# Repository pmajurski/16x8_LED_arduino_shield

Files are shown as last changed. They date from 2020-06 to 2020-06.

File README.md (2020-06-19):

# 16x8_LED_arduino_shield
16x8 LED display shield for Arduino Uno 

# Overview
This project is a custom shield for the Arduino Uno R3 and the controlling code. The display is two LuckyLight 8x8 LED matrices driven by two MAX7219 chips. Inputs for directional control, mode select, and brightness.
The display runs creatively named "display processes" which are relatively easy to create and add in. Display processes are broken up into animations and games. Animations can be static images, looping sequences of frames (ie gif), or animated sprites. Animations are non-interactive and ignore directional input. Games are interactive and use directional input.

# Controls
- Select toggles directional input between the current running process and mode select.
- Mode select: left / right cycles between animations, up / down cycles between games.
- Games are paused during mode select. Pressing select will unpause the active process. Animations ignore pause and will run during mode select.
- Brightness controls increase / decrease brightness. Default brightness can be adjusted in DisplayDriver.h

# Specs
- Display refresh and input polling at 50 Hz
- Powered by barrel jack connected to 9V battery. Optionally powered by Arduino Uno's barrel jack or USB.
- Display resolution of 16x8 pixels. Coordinate system is (y,x) with origin at top left corner. Y increases down, x increases right.
- Display draws roughly 340mA at full brightness.
 
# Creating new display processes
- Create a new child class of DisplayProcess
- Update animeProcesses or gameProcesses and their corresponding counts in .ino file.
- Display can be written to via a 16x8-bit frame buffer or 16x8-byte game matrix (which is then written to the frame buffer). 
- All processes share the frame buffer and game matrix.
- Sprites.cpp contains full frames stored in PROGMEM, which can be loaded directly into the frame buffer.

# Datasheets
- [MAX7219](https://www.sparkfun.com/datasheets/Components/General/COM-09622-MAX7219-MAX7221.pdf)
- [LuckyLight 8x8 LED matrix](https://cdn-shop.adafruit.com/datasheets/1820_KWM-R30881XPGB.pdf)

# Acknowledgements
- [forrestbao's kicad Arduino Uno shield footprint](https://github.com/forrestbao/arduino-kicad-library)
- [Adafruit Mini LED Gamer](https://github.com/adafruit/Adafruit_Learning_System_Guides/tree/master/Mini_LED_Gamer) - code for interrupt setup and modified snake game
- [MAX7219 driver wiring set up](https://playground.arduino.cc/Main/MAX72XXHardware/)

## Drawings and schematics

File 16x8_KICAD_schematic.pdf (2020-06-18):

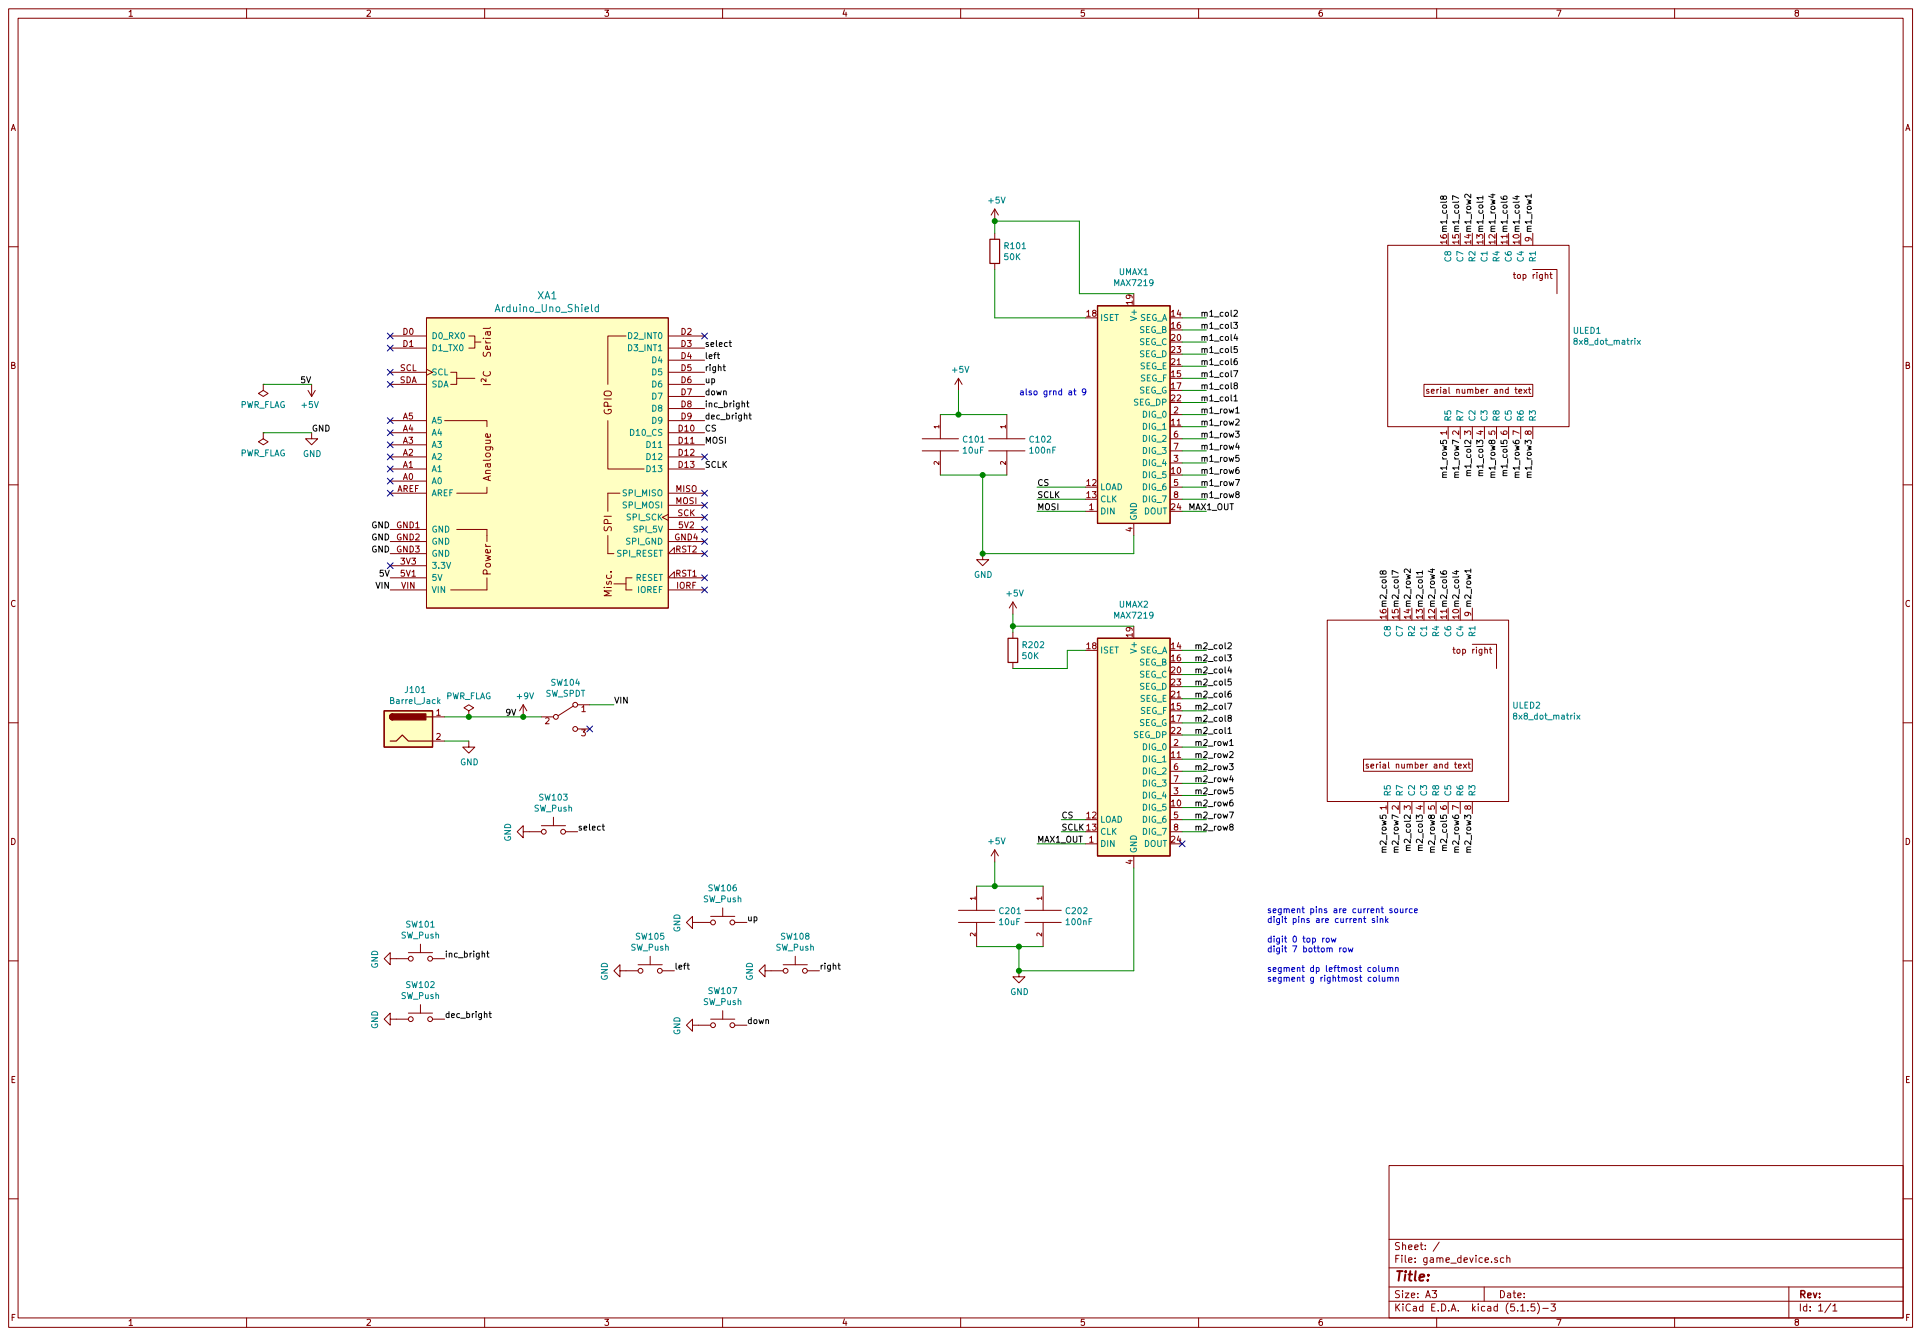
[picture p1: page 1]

serial number and text

segment pins are current source
digit pins are current sink

segment dp leftmost column
segment g rightmost column

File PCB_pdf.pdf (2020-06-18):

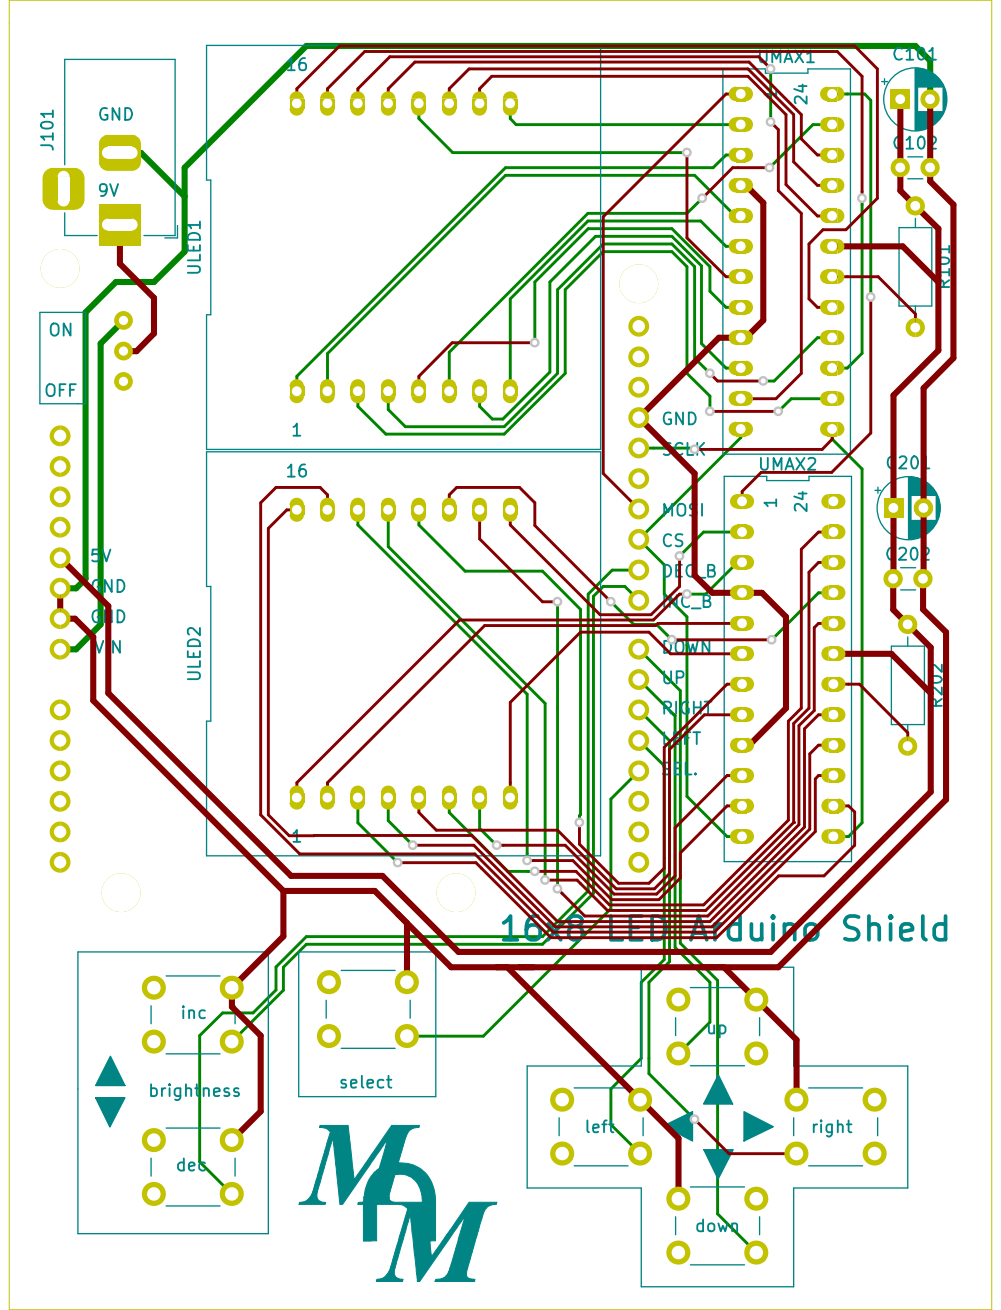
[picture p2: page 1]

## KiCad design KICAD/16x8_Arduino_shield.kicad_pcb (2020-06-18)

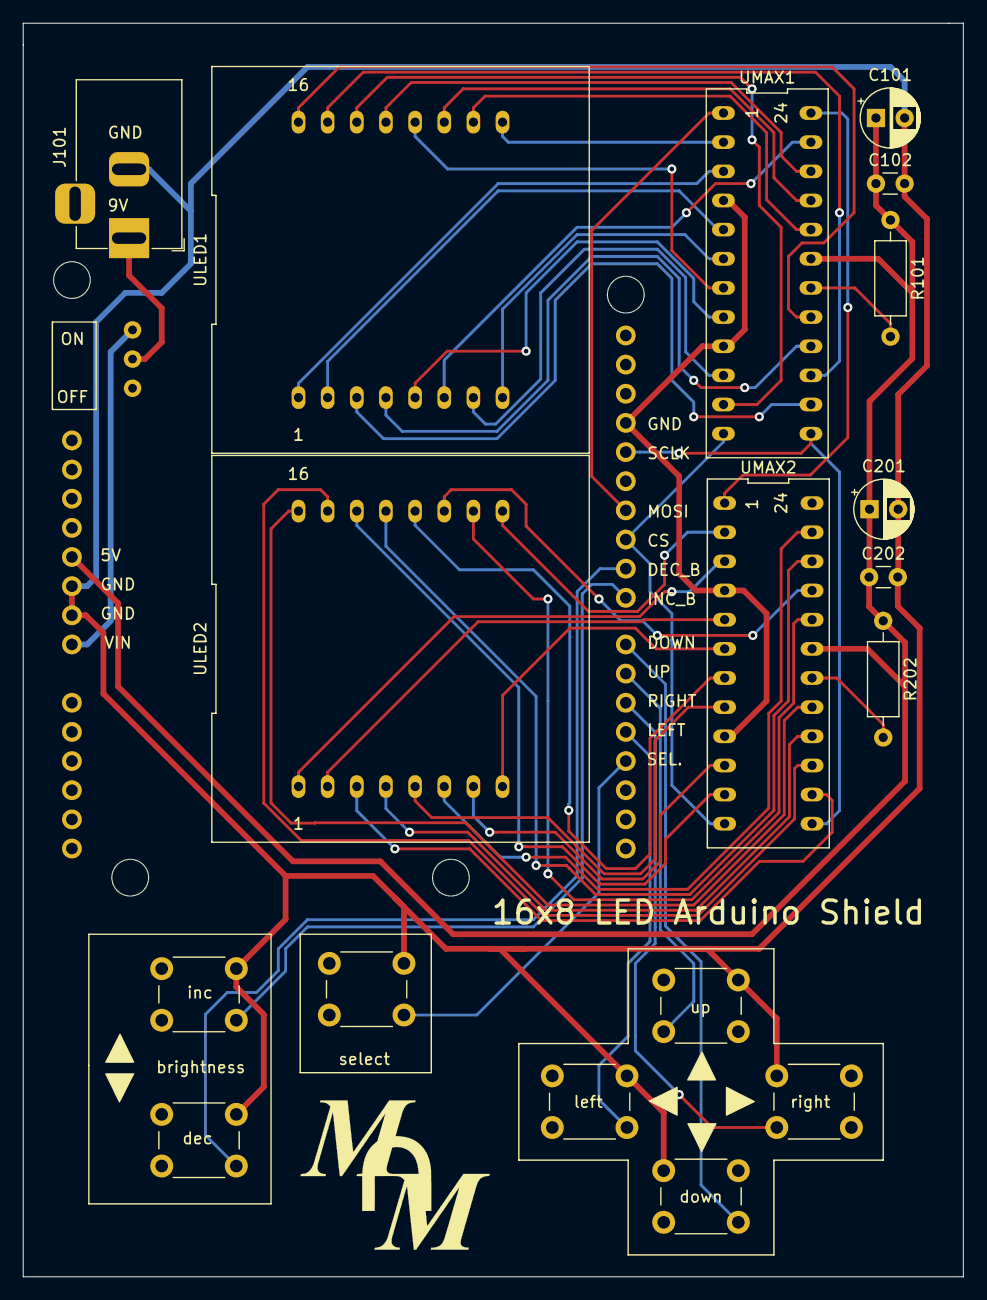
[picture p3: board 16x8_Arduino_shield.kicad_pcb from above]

Board: 2 copper layers, 81.9 x 109.2 mm, 20 parts (0 on the bottom side), 49 nets.

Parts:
C101, C201: 10uF; CP_Radial_D5.0mm_P2.50mm
C102, C202: 100nF; C_Disc_D3.0mm_W1.6mm_P2.50mm
J101: Barrel_Jack; BarrelJack_Horizontal
R101, R202: 50K; R_Axial_DIN0207_L6.3mm_D2.5mm_P10.16mm_Horizontal
SW104: SW_SPDT; SPDT_switch_custom
ULED1, ULED2: 8x8_dot_matrix; LuckyLight_8x8_LED_matrix
UMAX1, UMAX2: MAX7219; MAX2719_custom
XA1: Arduino_Uno_Shield
dec: SW_Push; SW_PUSH_6mm
down: SW_Push; SW_PUSH_6mm
inc: SW_Push; SW_PUSH_6mm
left: SW_Push; SW_PUSH_6mm
right: SW_Push; SW_PUSH_6mm
select: SW_Push; SW_PUSH_6mm
up: SW_Push; SW_PUSH_6mm

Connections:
+5V: C101.1, C102.1, C201.1, C202.1, R101.1, R202.1, UMAX1.19, UMAX2.19, XA1.5V1
+9V: J101.1, SW104.2
/CS: UMAX1.12, UMAX2.12, XA1.D10
/MAX1_OUT: UMAX1.24, UMAX2.1
/MOSI: UMAX1.1, XA1.D11
/SCLK: UMAX1.13, UMAX2.13, XA1.D13
/VIN: SW104.1, XA1.VIN
/dec_bright: XA1.D9, dec.2
/down: XA1.D7, down.2
/inc_bright: XA1.D8, inc.2
/left: XA1.D4, left.2
/m1_col1: ULED1.13, UMAX1.22
/m1_col2: ULED1.3, UMAX1.14
/m1_col3: ULED1.4, UMAX1.16
/m1_col4: ULED1.10, UMAX1.20
/m1_col5: ULED1.6, UMAX1.23
/m1_col6: ULED1.11, UMAX1.21
/m1_col7: ULED1.15, UMAX1.15
/m1_col8: ULED1.16, UMAX1.17
/m1_row1: ULED1.9, UMAX1.2
/m1_row2: ULED1.14, UMAX1.11
/m1_row3: ULED1.8, UMAX1.6
/m1_row4: ULED1.12, UMAX1.7
/m1_row5: ULED1.1, UMAX1.3
/m1_row6: ULED1.7, UMAX1.10
/m1_row7: ULED1.2, UMAX1.5
/m1_row8: ULED1.5, UMAX1.8
/m2_col1: ULED2.13, UMAX2.22
/m2_col2: ULED2.3, UMAX2.14
/m2_col3: ULED2.4, UMAX2.16
/m2_col4: ULED2.10, UMAX2.20
/m2_col5: ULED2.6, UMAX2.23
/m2_col6: ULED2.11, UMAX2.21
/m2_col7: ULED2.15, UMAX2.15
/m2_col8: ULED2.16, UMAX2.17
/m2_row1: ULED2.9, UMAX2.2
/m2_row2: ULED2.14, UMAX2.11
/m2_row3: ULED2.8, UMAX2.6
/m2_row4: ULED2.12, UMAX2.7
/m2_row5: ULED2.1, UMAX2.3
/m2_row6: ULED2.7, UMAX2.10
/m2_row7: ULED2.2, UMAX2.5
/m2_row8: ULED2.5, UMAX2.8
/right: XA1.D5, right.2
/select: XA1.D3, select.2
/up: XA1.D6, up.2
GND: C101.2, C102.2, C201.2, C202.2, J101.2, UMAX1.4, UMAX1.9, UMAX2.4, UMAX2.9, XA1.GND1, XA1.GND2, XA1.GND3, dec.1, down.1, inc.1, left.1, right.1, select.1, up.1
unnamed: R101.2, UMAX1.18
unnamed: R202.2, UMAX2.18

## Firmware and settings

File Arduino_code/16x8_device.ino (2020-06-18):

#include "Arduino.h"
#include "displayprocess.h"
#include "beatingheart.h"
#include "snake.h"
#include "mazegame.h"
#include "mugwithsteam.h"
#include "inchworm.h"
#include "icicles.h"
#include "screensaver.h"
#include "dwarfface.h"

using namespace DirectionInput;  //enum namespace for DisplayProcess move inputs

//defines pin numbers for input signals
enum InputSignal: uint8_t {
    SELECT_BUTTON = 3,
    LEFT_BUTTON = 4,
    RIGHT_BUTTON = 5,
    UP_BUTTON = 6,
    DOWN_BUTTON = 7,
    INCREASE_BRIGHTNESS = 8,
    DECREASE_BRIGHTNESS = 9,
    NO_SIGNAL = 255  //pin number 255 does not exist, used as no input
};

const uint8_t NUM_INPUTS = 7;  //number input pins used
const InputSignal INPUT_PINS[] = {
        SELECT_BUTTON,
        LEFT_BUTTON,
        RIGHT_BUTTON,
        UP_BUTTON,
        DOWN_BUTTON,
        INCREASE_BRIGHTNESS,
        DECREASE_BRIGHTNESS
};

//definite debounce and input cooldown
const uint8_t INPUT_COOLDOWN_CYCLES = 5;  //in refresh cycles - 5 = 100ms
const uint8_t DEBOUNCE_DELAY = 3;  //debounce minimum cycles for active state to count as valid input signal

//display processes available; MINIMUM of one of each process
DisplayProcess *gameProcesses[] = {
        new Snake(),
        new MazeGame()
};
DisplayProcess *animeProcesses[] = {
        new MugWithSteam(),
        new InchWorm(),
        new BeatingHeart(),
        new Icicles(),
        new ScreenSaver(),
        new DwarfFace()
};

const uint8_t NUM_GAMES = 2;
const uint8_t NUM_ANIMES = 6;
const uint8_t INITAL_ANIME = 5;  //index of anime process loaded on power up

uint8_t currentGame = 0;  //game process active or last active when in anime process
uint8_t currentAnime = INITAL_ANIME;  //anime process active or last active when in game process
DisplayProcess *activeProcess = animeProcesses[currentAnime];  //boots into an animation

//ISR volatile variables
volatile bool refreshDisplay = false;
volatile bool modeSelect = false;

//input handler variables
volatile uint8_t buttonHoldTimes[NUM_INPUTS] = {0};  //corresponds to elements of INPUT_PINS
volatile InputSignal inputBuffer = NO_SIGNAL;
volatile uint8_t inputCooldown = 0;

//enum type used for input directions in display processes
MoveDirection moveDirection = NO_INPUT;


//function prototypes
void inputHandler();  //iterates over signal pins looking for active pins
void processButton(uint8_t pinIndex);  //reads pins and debounces
void switchProcess();  //changes active display process
uint8_t getProcessIndex(uint8_t size, uint8_t index, bool direction);  //finds next display process
void setup();
void loop();


//50Hz timer interrupt for refreshing display
ISR(TIMER1_OVF_vect) {
  inputHandler();  //reads input signals. Buffers valid debounced inputs
  refreshDisplay = true;  //next loop() display process updates
}

void inputHandler() {
  inputBuffer = NO_SIGNAL;

  if (inputCooldown == 0) {  //cooldown since last input has expired; new input is accepted
    for (uint8_t i = 0; i < NUM_INPUTS; ++i) {  //read current button states; iterates over INPUT_PINS
      processButton(i);  //reads, debounces input signal

      if (inputBuffer != NO_SIGNAL)  //exits input handler if signal is valid
        return;
    }
  }
  else {  //cooldown between button presses is not over
    inputCooldown--;
  }
}

void processButton(uint8_t pinIndex) {
  if (digitalRead(INPUT_PINS[pinIndex]) == LOW) {  //determines if input is active
    buttonHoldTimes[pinIndex]++;

    if (buttonHoldTimes[pinIndex] > DEBOUNCE_DELAY) {  //signal active for longer than debounce period
      inputBuffer = INPUT_PINS[pinIndex];
      inputCooldown = INPUT_COOLDOWN_CYCLES;

      for (uint8_t j = 0; j < NUM_INPUTS; ++j)  //resets button hold times
        buttonHoldTimes[j] = 0;
    }
  }
  else {  //input signal is inactive, button hold time is reset
    buttonHoldTimes[pinIndex] = 0;
  }
}

void switchProcess() {
  switch (moveDirection) {  //computes next process index and updates activeProcess
    case LEFT:  //previous anime
      currentAnime = getProcessIndex(NUM_ANIMES, currentAnime, 0);
      activeProcess = animeProcesses[currentAnime];
      break;
    case RIGHT:  //next anime
      currentAnime = getProcessIndex(NUM_ANIMES, currentAnime, 1);
      activeProcess = animeProcesses[currentAnime];
      break;
    case UP:  //next game
      currentGame = getProcessIndex(NUM_GAMES, currentGame, 1);
      activeProcess = gameProcesses[currentGame];
      break;
    case DOWN:  //previous game
      currentGame = getProcessIndex(NUM_GAMES, currentGame, 0);
      activeProcess = gameProcesses[currentGame];
  }

  activeProcess->init();  //init new process
}

uint8_t getProcessIndex(uint8_t size, uint8_t index, bool direction) {
  //returns new index; handles wrap around logic
  //direction: 1-increments; 0-decrements
  if (direction) {  //forward move
    if (index < size - 1)
      return ++index;
    return 0;  //wraps around to beginning of array
  }
  else {  //backwards move
    if (index != 0)
      return --index;
    return (size - 1);  //wraps around to end of array
  }
}

void setup() {
  //configures all input pins as active low with internal pullup
  for (uint8_t i = 0; i < NUM_INPUTS; ++i)
    pinMode(INPUT_PINS[i], INPUT_PULLUP);

  randomSeed(analogRead(5));  //seeds random generation with unconnected pin
  for (uint8_t i = 0; i < 4; ++i) //skips first randoms, always same
    random();


  // taken from https://github.com/adafruit/Adafruit_Learning_System_Guides/blob/master/Mini_LED_Gamer/
  // ADC clock configurations
  byte ADPS_32 = _BV(ADPS2)|_BV(ADPS0);
  byte ADPS_128 = _BV(ADPS2)|_BV(ADPS1)|_BV(ADPS0);

  //ADC: 16MHz/16=1MHz
  ADCSRA &= ~ADPS_128;              // clean out ADPS
  ADCSRA |= ADPS_32;                // set Division Factor

  // Timer1 overflow interrupt setup
  TCNT1 = 0;                        // reset the counter
  ICR1 = 19999;                     // top value of the counter (16*10^6Hz/2000000*20000us/8-1) -> 1/20000us = 50Hz
  TCCR1A = 0;                       // clear TCCR1A (not used)
  TCCR1B = _BV(WGM13) | _BV(CS11);  // mode 8(PWM), set prescalar=8;
  TIMSK1 = _BV(TOIE1);              // Enable Overflow Interrupt


  activeProcess->init();  //start first display process
}

void loop() {
  if (refreshDisplay) {
    moveDirection = NO_INPUT;

    //interprets input signal
    switch (inputBuffer) {  //only 1 input signal can be generated at a time
      case SELECT_BUTTON:
        if (modeSelect)  //leaving mode select
          activeProcess->unpause();
        else  //entering mode select
          activeProcess->pause();
        modeSelect = !modeSelect;  //switches how directional input is handled
        break;
      case INCREASE_BRIGHTNESS:
        DisplayProcess::increaseBrightness();
        break;
      case DECREASE_BRIGHTNESS:
        DisplayProcess::decreaseBrightness();
        break;
      case LEFT_BUTTON:
        moveDirection = LEFT;
        break;
      case RIGHT_BUTTON:
        moveDirection = RIGHT;
        break;
      case UP_BUTTON:
        moveDirection = UP;
        break;
      case DOWN_BUTTON:
        moveDirection = DOWN;
    }

    //direction input is handled differently in mode select. the current display process is changed and init
    if (modeSelect and moveDirection != NO_INPUT)
      switchProcess();  //changes active process
    else
      activeProcess->run(moveDirection);  //updates process, stepping one frame

    refreshDisplay = false;
  }
}

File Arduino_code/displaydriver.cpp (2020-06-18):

#include "displaydriver.h"

DisplayDriver::DisplayDriver() {
  intensity_ = DEFAULT_INTENSITY;
  configSPI();
  disableDisplayTest();  //prevents LED displays being placed into display test mode on uploading code to Arduino
  configDisplay();
  clearDisplay();
}

void DisplayDriver::configSPI() {
  //SPI.begin();

  //configures SPI pins
  pinMode(CHIP_SELECT, OUTPUT);
  pinMode(MASTEROUT_SLAVEIN, OUTPUT);
  pinMode(SERIAL_CLK, OUTPUT);
  digitalWrite(CHIP_SELECT, LOW);  //drives CHIP_SELECT (LOAD on MAX7219) low

}

void DisplayDriver::configDisplay() {
  //transmits op codes to set intensity, disable shutdown, set scan all digits
  uint16_t intensity = INTENSITY_REG + intensity_;
  uint16_t spiData[] = {intensity, intensity, SCAN_ALL, SCAN_ALL, SHUTDOWN_DISABLE, SHUTDOWN_DISABLE};
  spiTransmit(spiData, 6);
}

void DisplayDriver::disableDisplayTest() {
  uint16_t spiData[] = {DISPLAY_TEST_REG, DISPLAY_TEST_REG};  //normal operation code is opcode followed by all zeros
  spiTransmit(spiData, 2);
}

void DisplayDriver::increaseBrightness() {
  if (intensity_ + INTENSITY_STEP_SIZE < MAX_INTENSITY)  //prevents overflow
    intensity_ += INTENSITY_STEP_SIZE;
  else
    intensity_ = MAX_INTENSITY;

  uint16_t spiData[] = {INTENSITY_REG + intensity_, INTENSITY_REG + intensity_};
  spiTransmit(spiData, 2);
}

void DisplayDriver::decreaseBrightness() {
  if (intensity_ > INTENSITY_STEP_SIZE)  //prevents underflow
    intensity_ -= INTENSITY_STEP_SIZE;
  else
    intensity_ = MIN_INTENSITY;

  uint16_t spiData[] = {INTENSITY_REG + intensity_, INTENSITY_REG + intensity_};
  spiTransmit(spiData, 2);
}

void DisplayDriver::updateDisplay(const uint8_t frameBuffer[16]) {
  //framebuffer size is 16; each index is row on display
  //rewrites entire display with frameBuffer; lower indexes are upper 8x8 matrix LEDs

  //MAX7219 data is MSB format
  //rows 0-7 upper, rows 8-15 lower; send in pairs eg 0,8 1,9

  //DIG outputs sink current - cathode, row select. set up so DIG0 is top most row
  //SEG outputs source current - set up so SEG_DP is left most column, SEG_G rightmost
  //DATA IN - D7 -> D0; places right into register in same order

  //convert index in buffer into digit code for both displays in parallel
  //rows buffered in packets as: 0,8,1,9,2,10,3,11,4,12,5,13,6,14,7,15

  uint16_t spiData[16] = {0};  //data packets to update display. One per row
  uint16_t rowAddress = 0x0100;  //initial row address
  uint8_t bufferRow = 0;  //rows read in parallel from frameBuffer

  //iterates over frameBuffer sequentially reading bufferRow and bufferRow + 8 to program both displays at same time
  for (uint8_t i = 0; i < 16; i+=2) {
    spiData[i] = rowAddress + frameBuffer[bufferRow+8];  //second display (lower 8x8) first code in packet
    spiData[i+1] = rowAddress + frameBuffer[bufferRow];
    rowAddress += 0x0100;  //increments 'digit' register address
    bufferRow++;
  }

  spiTransmit(spiData, 16);  //send commands to MAX7219's
}

void DisplayDriver::clearDisplay() {
  uint16_t spiData[16] = {0};  //data packets to update display. One per row
  uint16_t rowAddress = 0x0100;  //initial row address in data packet

  for (uint8_t i = 0; i < 16; i+=2) {  //row address is in upper 8-bits. lower 8-bits are zero -> turn off row LEDs
    spiData[i] = rowAddress;
    spiData[i+1] = rowAddress;
    rowAddress += 0x0100;  //increments 'digit' register address
  }

  spiTransmit(spiData, 16);  //send commands to MAX7219's
}

void DisplayDriver::disableDisplay() {
  uint16_t spiData[] = {SHUTDOWN_ENABLE, SHUTDOWN_ENABLE};
  spiTransmit(spiData, 2);
}

void DisplayDriver::enableDisplay() {
  uint16_t spiData[] = {SHUTDOWN_DISABLE, SHUTDOWN_DISABLE};
  spiTransmit(spiData, 2);
}

void DisplayDriver::spiTransmit(const uint16_t spiData[], uint8_t numPackets) {
  //initializes SPI: max clock of 10MHz, most significant bit first, SPI mode 0
  SPI.beginTransaction(SPISettings(10000000, MSBFIRST, SPI_MODE0));

  //transfers 2 commands to 2 MAX7219
  for (uint8_t i = 0; i < numPackets; i+=2) {
    SPI.transfer16(spiData[i]);
    SPI.transfer16(spiData[i+1]);

    //latches commands in MAX7219's
    digitalWrite(CHIP_SELECT, HIGH);
    digitalWrite(CHIP_SELECT, LOW);
  }

  SPI.endTransaction();
}

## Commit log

2020-06-18 code and pdfs from kicad
2020-06-18 kicad files
    [16x8_Arduino_shield.kicad_pcb, 16x8_Arduino_shield.sch]
